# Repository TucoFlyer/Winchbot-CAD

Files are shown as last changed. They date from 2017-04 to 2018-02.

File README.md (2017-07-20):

# Winchbot-CAD

Mechanical design for a 1D robot that can raise and lower a load suspended on paracord.

Multiple winchbots can be networked via Ethernet to move a load in 3D space.

* Mostly 3D printed parts
* Compact and fully enclosed
* Designed for approx 5kg max dynamic load and 2.5kg static
* Plenty of spool space for moving loads in very large spaces
* Closed loop control of cord movement using a feedback capstan
* Force sensing using a load cell, for load position feedback and jam detection

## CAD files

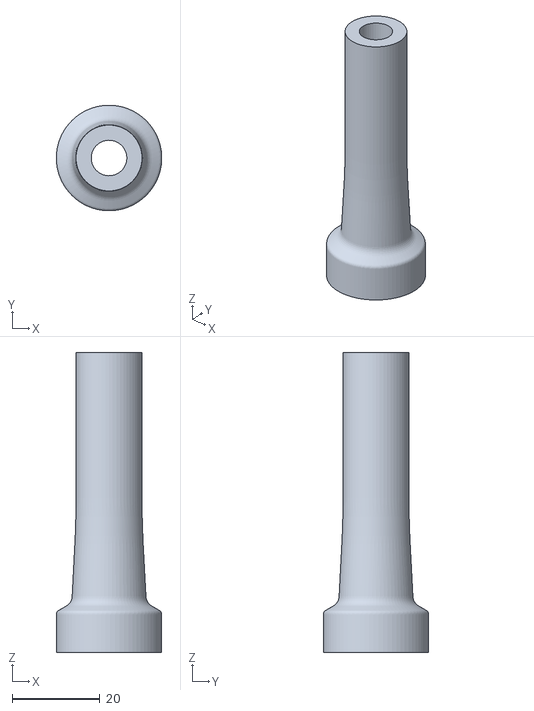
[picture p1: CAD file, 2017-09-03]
bot/winchbot-rollertube-5.stl
24.0 x 24.0 x 68.3

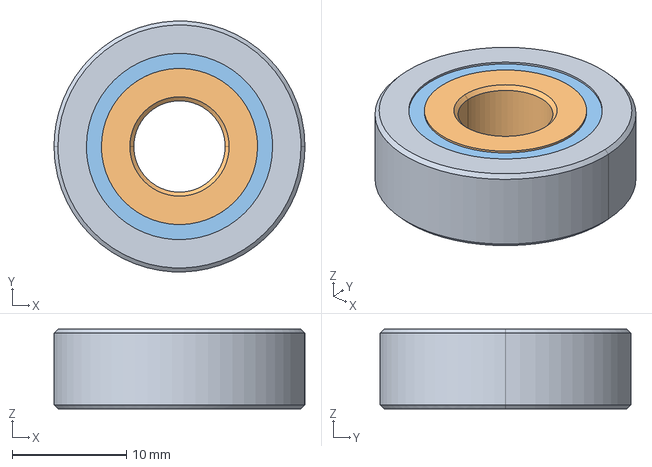
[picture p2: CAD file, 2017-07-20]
references/608-bearing.stp
22.0 x 22.0 x 7.00 mm

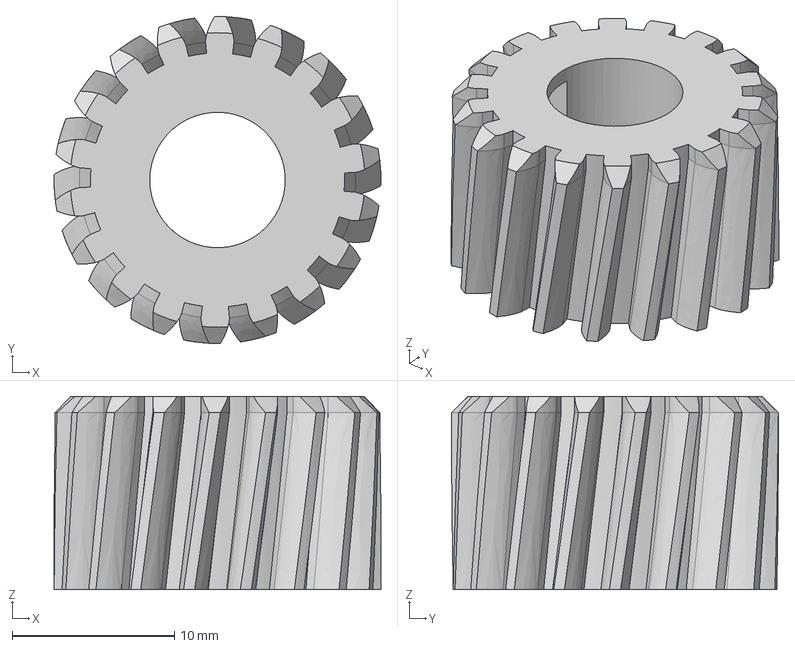
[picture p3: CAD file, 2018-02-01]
repairs/Replacement Gear for TS-53Z868-30 v6.step
20.2 x 20.2 x 11.9 mm

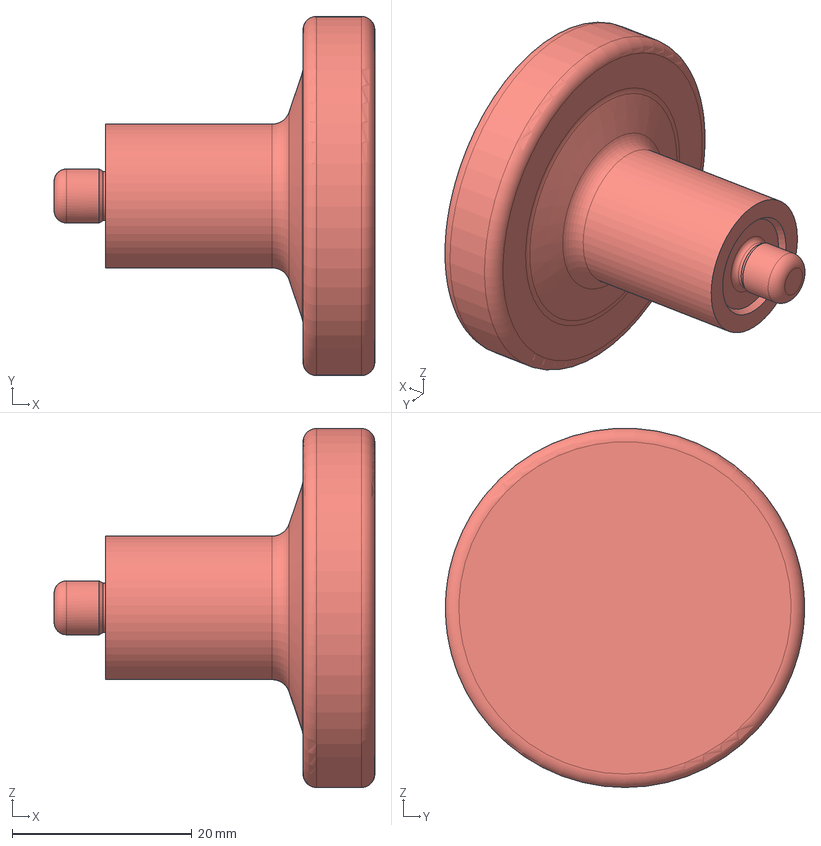
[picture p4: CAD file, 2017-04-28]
tools/606 Bearing Press v3.step
35.7 x 40.0 x 40.0 mm

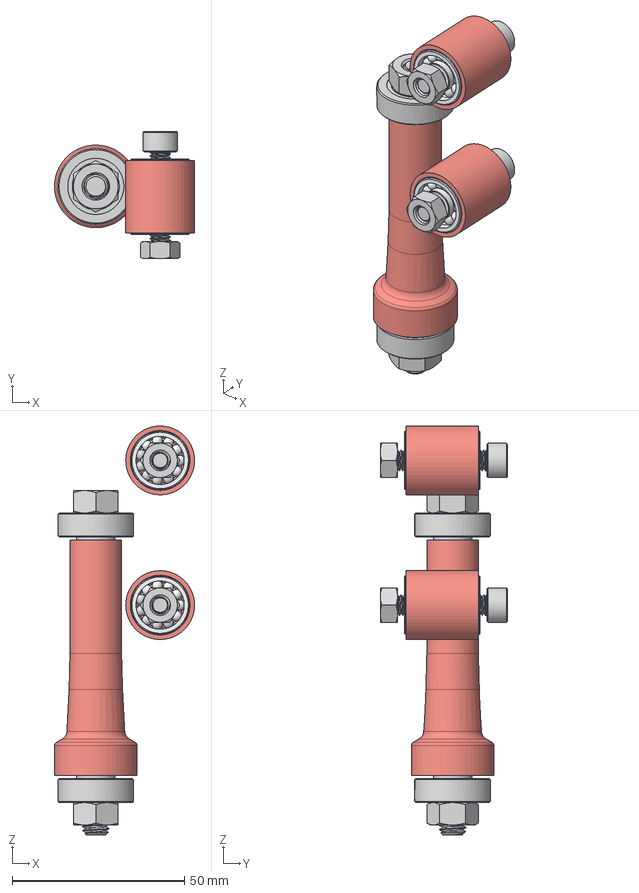
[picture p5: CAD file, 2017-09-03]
bot/Side Rollers.stp
40.7 x 37.0 x 118.7 mm
90591A161 x 2
5972K501 x 2
m8x100_rod v1
606 v2 x 4
91290A332 x 2
winchbot-shortroller-1 x 2
winchbot-shortrtube-1 x 2
90591A151 x 2
winchbot-rollertube
SpeedWasher x 2

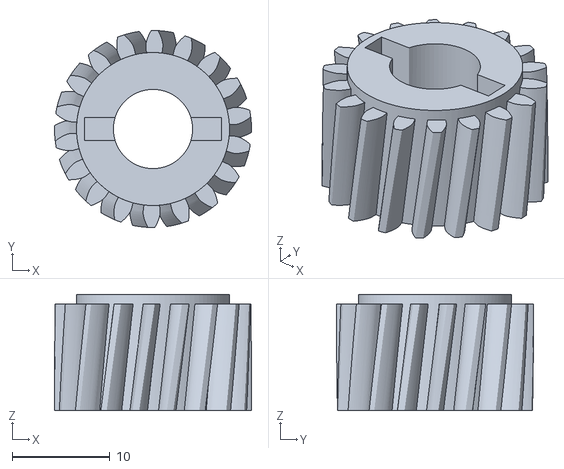
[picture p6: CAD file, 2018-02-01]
repairs/tsiny-plastic-helical-gear-1.stl
20.2 x 20.2 x 11.9

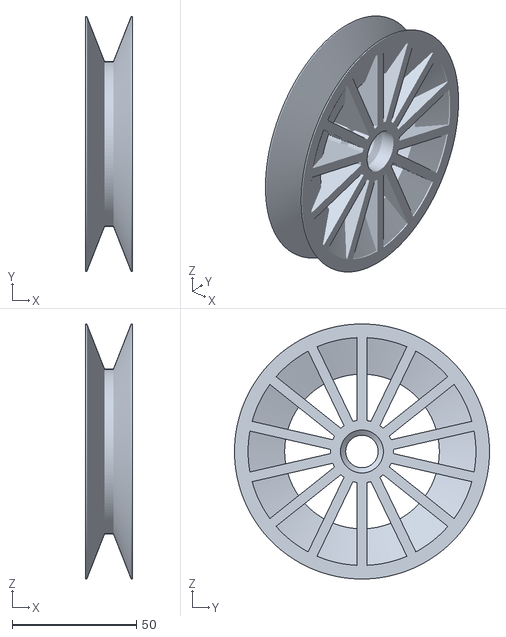
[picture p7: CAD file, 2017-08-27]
bot/extpulley-wheel-2.stl
18.8 x 102.6 x 102.6

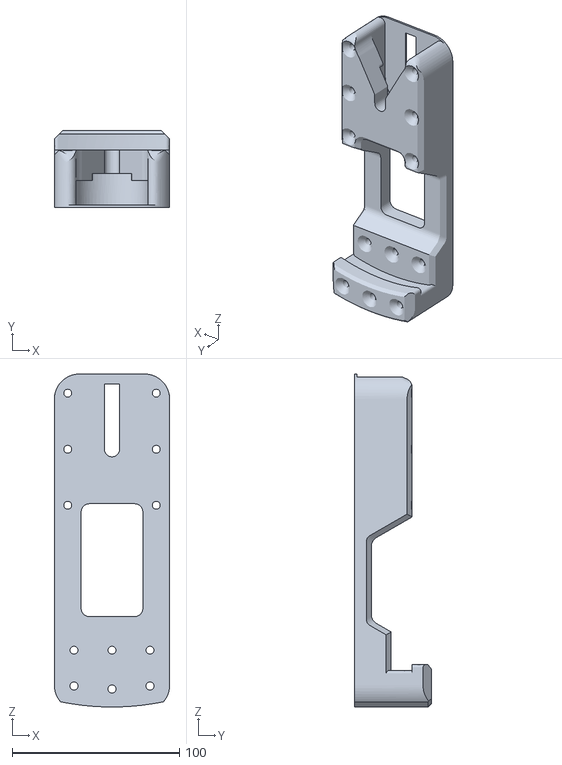
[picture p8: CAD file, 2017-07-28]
bot/winchbot-wall-plate-2.stl
68.9 x 45.8 x 199.0

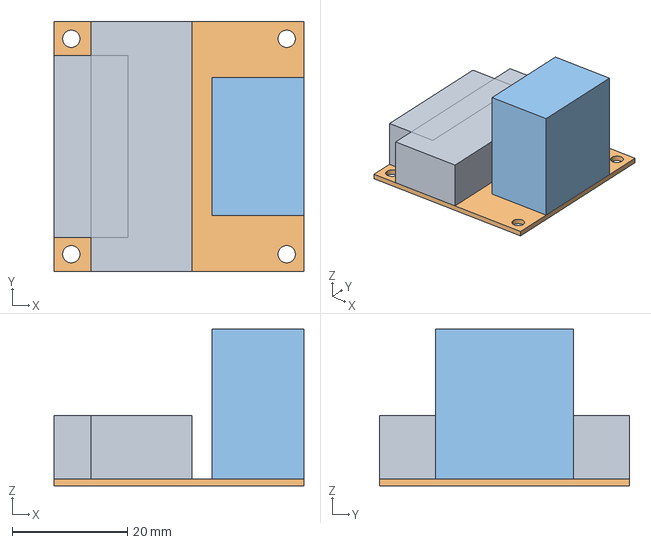
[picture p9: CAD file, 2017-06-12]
references/L298N Breakout.stp
43.4 x 43.4 x 27.2 mm

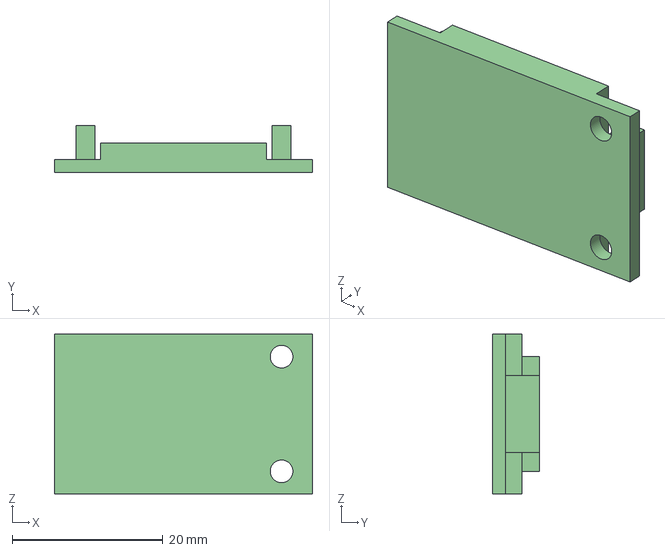
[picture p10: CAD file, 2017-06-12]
references/HX711 Breakout v3.step
34.2 x 6.20 x 21.2 mm

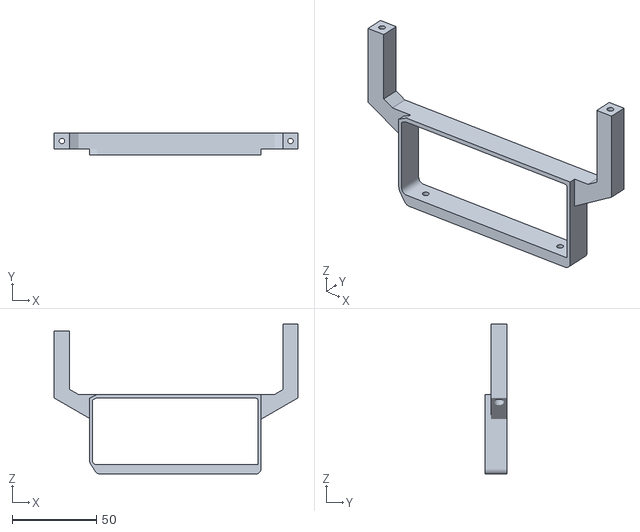
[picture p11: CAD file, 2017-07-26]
bot/winchbot-psuarms-2.stl
145.0 x 13.0 x 89.1

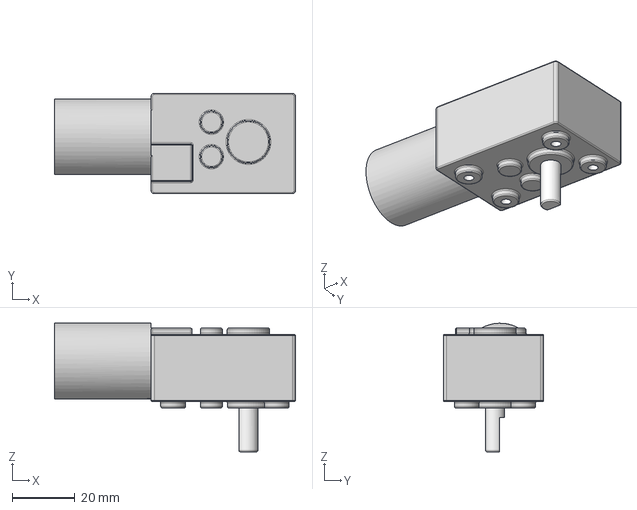
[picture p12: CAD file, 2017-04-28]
references/Gear Motor ZWL-FP69i v8.step
76.8 x 32.0 x 41.0 mm

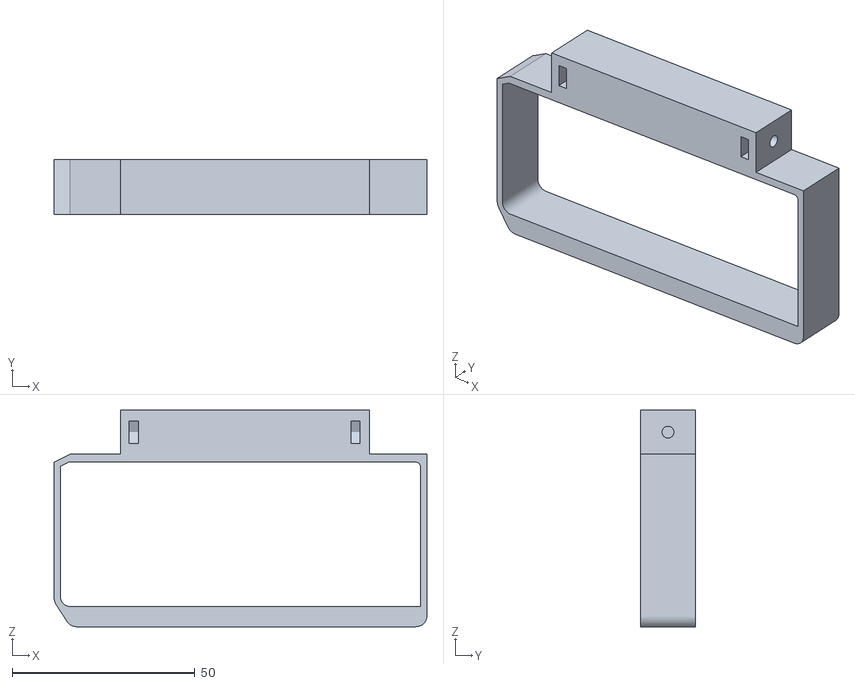
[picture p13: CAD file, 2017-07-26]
bot/winchbot-psuring-2.stl
102.0 x 15.2 x 59.2

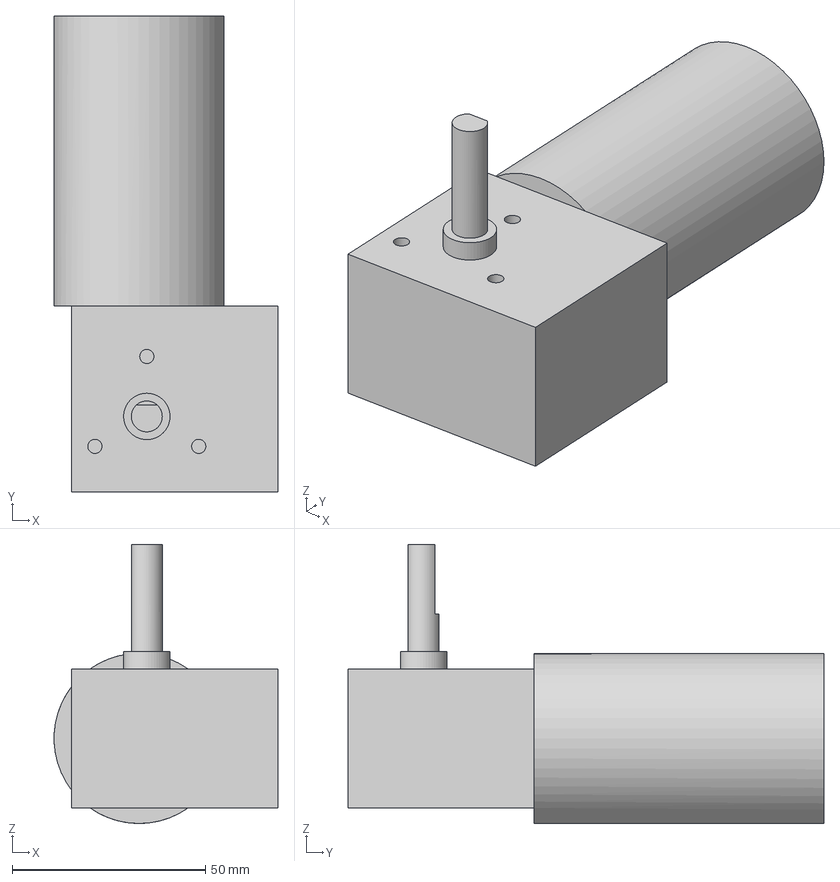
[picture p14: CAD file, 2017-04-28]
references/tsinymotor-TS-53GZ868DIM v3.step
57.9 x 123.0 x 72.2 mm

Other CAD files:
references/InvoluteGear_1.dxf
tools/606-bearing-press.stl
repairs/tsiny-plastic-helical-gear-3.stl
repairs/tsiny-plastic-helical-gear-2.stl
bot/Power Board.f3d
bot/Spool.step
bot/extpulley-frameA-1.stl
bot/extpulley-frameB-1.stl
bot/extpulley-spacer-1.stl
bot/lower-shell-interface.f3d
bot/winchbot-eframe-mcuside-1.stl
bot/winchbot-eframe-powerside-1.stl
bot/winchbot-encoder-capstan.stl
bot/winchbot-flatroller-1.stl
bot/winchbot-frame-drivehalf-4.stl
bot/winchbot-frame-idlerhalf-4.stl
bot/winchbot-loadcell-bracket-1.stl
bot/winchbot-motor-flexgear-2.stl
bot/winchbot-motor-hub-2.stl
bot/winchbot-nut-wheel-1.stl
bot/winchbot-shortroller-3.stl
bot/winchbot-shortrtube-3.stl
bot/winchbot-small-idler.stl
bot/winchbot-spool-core-3.stl
bot/winchbot-spool-driveside-3.stl
bot/winchbot-spool-flexgear-2.stl
bot/winchbot-spool-idlerside-3.stl
bot/winchbot-topbracket-2.f3d
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

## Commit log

2017-04-28 Work so far on Winchbot CAD
    [606 Bearing Press v3.iges, 606 Bearing Press v3.step, 606 v2.f3d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]
2017-06-12 Checking in random F360 exports from winchbot
    [HX711 Breakout v2.f3d, HX711 Breakout v3.iges, HX711 Breakout v3.step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]
2017-06-23 Files from this week's geared spool test
    And some references for the next revision.
    [InvoluteGear_1.dxf, Old Spool and Motor v10.step, flexgear-motor-side-1.stl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]
2017-06-27 Lots more winchbot CAD, geared design ready to begin printing
    [flexgear-motor-side-1.stl, flexgear-spool-side-1.stl, gearhub-motor-side-1.stl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]
2017-06-28 Removing old versions, including 1st spool design
    [Encoder Capstan v21.iges, Encoder Capstan v21.step, Measurement Assembly v15.step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]
2017-07-01 Lots more work on the frame part for printability
    [winchbot-frame-drivehalf-4.stl, winchbot-frame-idlerhalf-4.stl, winchbot-shortroller-2.stl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]
2017-07-07 New spool, new mess
    Changes from yesterday's stream to add spool printability relief holes
    and a new knot recess in the center hub. These ended up making a huge
    mess of the already-completed frame component, so I've attempted to fix
    that up by reverting to an older version of the F3D file and
    re-importing the latest spool from STEP. This has reset the F360 version
    numbering.
    [Spool.step, winchbot-spool-core-3.stl, winchbot-spool-driveside-3.stl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]
2017-07-07 Removing old versions
    [Small Idler v13.iges, Spool and Motor v6.iges, Spool and Motor v6.step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]
2017-07-11 Updated Winchbot export, tweaking roller dimensions
    [winchbot-rollertube-2.stl, winchbot-rollertube-3.stl, winchbot-topbracket-1.stl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]
2017-07-11 Cleaning out old versions
    [winchbot-frame-drivehalf-3.stl, winchbot-frame-idlerhalf-3.stl, winchbot-rollertube-1.stl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]
2017-07-20 Winch mechanical design tested up to 2.5kg
    [608-bearing.stp, extpulley-frameA-1.stl, extpulley-frameB-1.stl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]
2017-07-23 Still working on electronics mounts`
    [Power Board.f3d, lower-shell-interface.f3d, winchbot-topbracket-2.f3d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]
2017-07-24 Electronics mount ready for printing
    [winchbot-eframe-mcuside-1.stl, winchbot-eframe-powerside-1.stl, winchbot-psuarms-1.stl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]
2017-07-26 Designs from yesterday, everything but the shell is done
    [winchbot-nut-wheel-1.stl, winchbot-psuarms-2.stl, winchbot-psuring-2.stl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]
2017-07-28 Shell design may be done
    [winchbot-shell-left-1.stl, winchbot-shell-right-1.stl, winchbot-wall-plate-1.stl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]
2017-07-31 Reinforce/thicken shell a bit to improve printability
    [winchbot-shell-left-2.stl, winchbot-shell-right-2.stl]
2017-08-01 Reinforce shell more, for printability
    [winchbot-shell-2.stp]
2017-08-04 More shell reinforcement
    This time with nurb surgery in rhino again, made all the outer shells
    2.5mm thick, and added solid areas at the front corners for additional
    support.
2017-08-07 Shell revision for reinforcement and printability
2017-08-27 New extpulley profile, old one was bad
    [extpulley-wheel-2.stl]
2017-08-27 Wall plate printability, strength changes in slicer
2017-08-31 Removing another old file
    [winchbot-psutray-1.stl]
2017-09-03 New rollertube to try and fix winch creaking
    - increasing outer diameter to increase strength and decrease rolling friction
    - same inner diameter, that seemed fine after drilling
    - shoulder on one side to help prevent tangles under low tension
    - space for 1mm "speed washer" spacers on either side
    [Side Rollers.stp, winchbot-rollertube-4.stl, winchbot-rollertube-5.stl]
2017-09-03 Delta printer seems not to be accurate enough here
2017-09-04 Reslice roller slower and cooler
    The last print had some problems with the outer layer falling over, but I
    hit it with the belt sander and used it anyway. For the other winches I'd
    like a cleaner print, so using the same model but slicing it slower and
    cooler.
2017-09-19 Reslice for printability and strength
2017-09-19 More printability fussing, problems with warping
2017-09-20 Another reslice, separate parts for extpulley frame, stronger, clear PLA
2018-02-01 Replacement gears for the winch motor
    [Replacement Gear for TS-53Z868-30 v6.f3d, Replacement Gear for TS-53Z868-30 v6.step, tsiny-plastic-helical-gear-1.stl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]
